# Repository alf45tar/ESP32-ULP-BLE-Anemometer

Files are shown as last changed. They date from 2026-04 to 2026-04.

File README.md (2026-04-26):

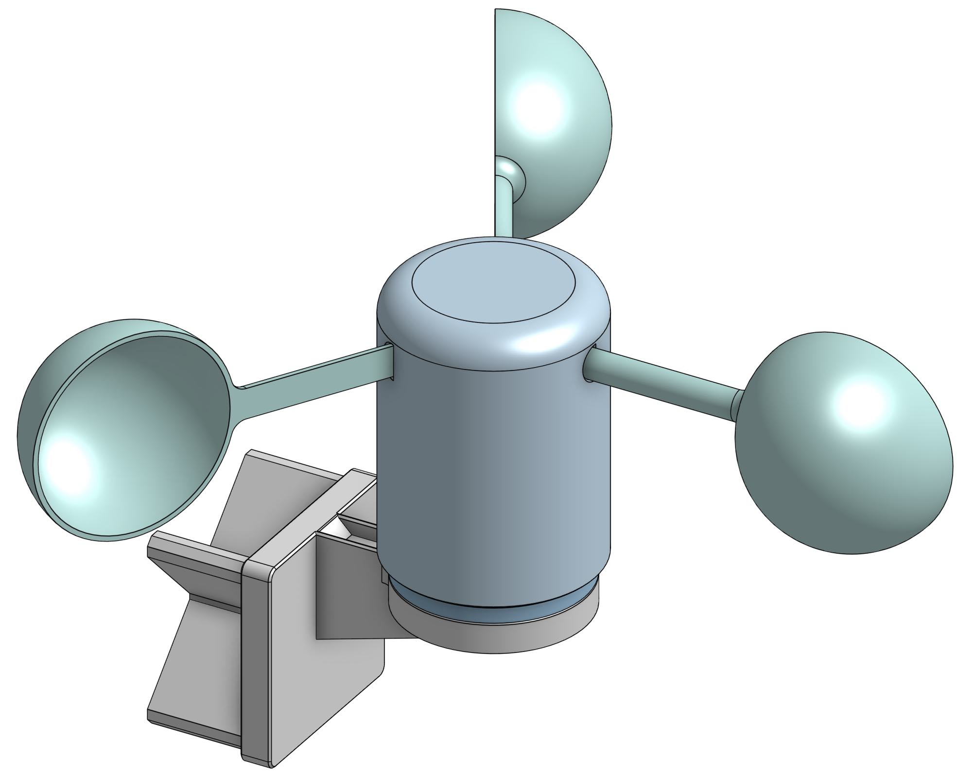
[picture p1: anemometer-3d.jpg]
3D Printed Anemometer


# 🌀 ESP32 ULP BLE Anemometer (BTHome V2)

A high-efficiency, battery-powered wind speed sensor (Anemometer) using the ESP32. This project leverages the **ULP (Ultra-Low Power) co-processor** to monitor wind pulses while the main CPU is in Deep Sleep, allowing for years of battery life.

## 🚀 Key Features

  * **Ultra-Low Power:** Can be as low as **\~15µA** in deep sleep on the ESP32 alone. Actual current depends on the board and any attached hardware. The main cores only wake up to calculate and transmit data.
  * **BTHome V2 Protocol:** Works natively with **Home Assistant** via Bluetooth—no custom integration or ESPHome YAML required. See [bthome.io](https://bthome.io).
  * **Intelligent Reporting:**
      * **Wind Detected:** Typically reports on the next 5-second wake cycle while wind is present.
      * **Change Detection:** Tries to report a speed change as soon as it is noticed on the next wake cycle.
      * **Heartbeat:** Sends a periodic "still alive" update, usually about every 60 seconds during calm periods.
  * **Hardware Debouncing:** ULP-based software sampling filters out mechanical reed switch "bounce."

-----

## 🛠 Hardware Requirements

1.  **ESP32 or ESP32-S3 Board**.
    * For ESP32-C6 check the [ESP32-C6](https://github.com/alf45tar/Anemometer) anemometer project.
3.  **Anemometer** (3-cup type with a Reed Switch).
4.  **Battery:** Li-ion 18650 or LiPo.

### Bill of Materials

| Item | Quantity | Notes |
| :--- | :--- | :--- |
| ESP32 board | 1 | Use a board with an onboard battery sensor (divider) if possible |
| 3D-printed anemometer | 1 | Main wind-sensing body |
| 608 bearing 8x22x7 mm | 1 | Very common bearing for shaft support |
| M3 heat-set insert | 1 | For connecting the main body to the support |
| M3 hex socket cap screw M3x12 | 1 | Fastens the main body to the support |
| Reed switch | 1 | Wind pulse sensor |
| Magnet 6x3 mm | 2 | For triggering the reed switch |
| Battery | 1 | Li-ion 18650 or LiPo |

### Wiring

Connect the reed switch between SENSOR_GPIO pin and GND.

For battery monitoring, a board with an onboard battery divider is recommended.

-----

## 💻 Installation

### 1\. Libraries Required

Install the following libraries via the Arduino Library Manager:

  * [**NimBLE-Arduino**](https://github.com/h2zero/NimBLE-Arduino) (Lightweight Bluetooth LE)
  * [**BTHomeV2-Arduino**](https://github.com/deeja/BTHomeV2-Arduino) (BTHome data formatting)

### 2\. Configuration

Adjust the constants at the top of the sketch to match your hardware:

```cpp
const float RADIUS_METERS      = 0.071; // Center to cup middle
const float CALIBRATION_FACTOR = 2.5;   // Aerodynamic factor
const int   PULSES_PER_REV     = 2;     // Number of magnets in your sensor
```

**Tuning Guide:**

* **RADIUS_METERS**: Measure from the center of the shaft to the center of a cup.
* **PULSES_PER_REV**: Set this to the number of magnet passes per full revolution.
* **CALIBRATION_FACTOR**: Adjust this if you want accurate wind-speed measurements. Compare the reading against a known wind source or a reference sensor, then increase or decrease this factor until they match closely.

If you are only using the anemometer for threshold-based automation, such as closing an awning with a Shelly device, a precise calibration is usually not required. In that case, a stable and repeatable reading is enough to trigger the chosen wind-speed threshold.

### 3\. Flash

Upload the code to your ESP32. Open the Serial Monitor (115200 baud) to verify the "Fresh Boot" and "Deep Sleep" cycles.

-----

## 🏠 Home Assistant Integration

1.  Ensure the **Bluetooth** integration is active in Home Assistant.
2.  The sensor will be automatically discovered as a **BTHome** device named **"Wind Sensor"**.
3.  Add it to your dashboard. The wind speed will appear as a sensor entity in `m/s`.

-----

## 🔌 Shelly Integration

If you are using **Shelly** devices, the anemometer can also be configured as a **virtual component** in your Shelly setup. This does **not** require Home Assistant.

Depending on the Shelly virtual component setup, you may need the ESP32 BLE address.
To print it directly from the board, upload this small sketch and read the value from the Serial Monitor:

```cpp
#include <Arduino.h>
#include <NimBLEDevice.h>

void setup() {
  Serial.begin(115200);
  NimBLEDevice::init("ESP32");
}

void loop() {
  BLEAddress localAddress = NimBLEDevice::getAddress();
  Serial.println(localAddress.toString().c_str());
  delay(1000);
}
```

### Example Use Case

Use the anemometer to automatically close an awning with a **Shelly 2PM Gen3** when wind speed gets too high, without any extra wiring between the wind sensor and the Shelly device. The anemometer broadcasts wind data over BLE, and Shelly handles the automation logic on its side. In this setup, the ESP32 board and battery are hidden inside the square bar, which also supports the anemometer using an interlocking fit (no screw required).

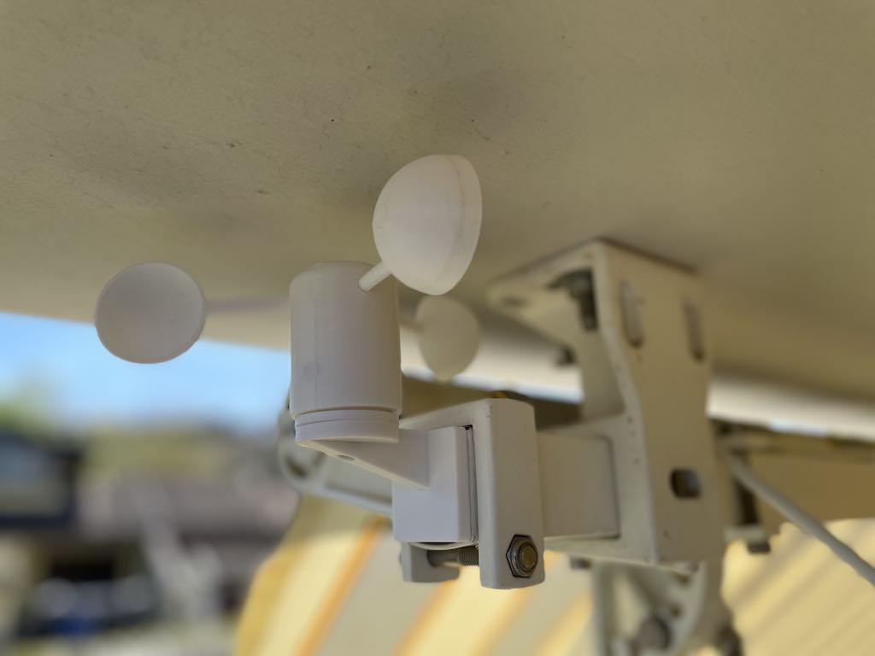
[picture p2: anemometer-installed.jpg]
Anemometer


-----

## 📉 Power Consumption Profile

  * **Deep Sleep (ULP Active):** \~15µA minimum, depending on the board and attached hardware
  * **BLE Transmission (1.5s):** \~100mA
  * **Total Battery Life:** \~1-2 years on a 2500mAh 18650 cell (depending on wind frequency).

-----

## 📜 License

This project is licensed under the MIT License - see the LICENSE file for details.

-----

## 🙌 Credits

  * **NimBLE-Arduino** by [h2zero](https://github.com/h2zero)
  * **BTHome V2** protocol by [bthome.io](https://bthome.io).

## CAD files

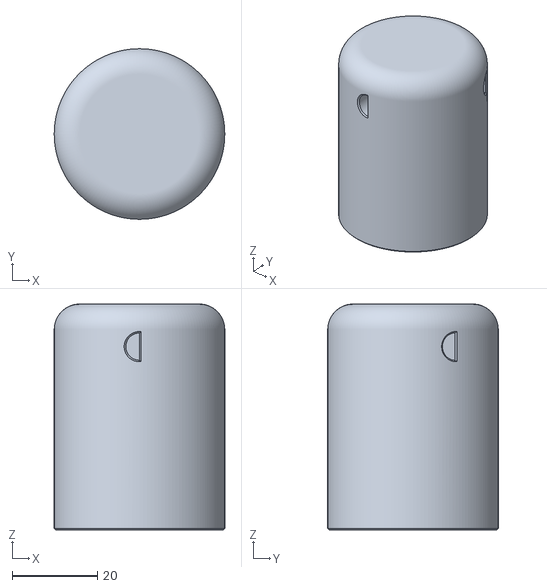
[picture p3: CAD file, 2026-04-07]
Body.stl
40.0 x 40.0 x 53.0

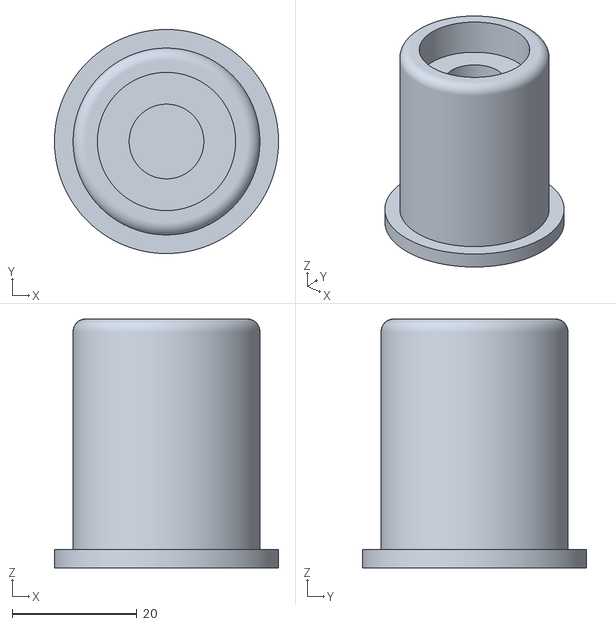
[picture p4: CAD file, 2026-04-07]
Base.stl
36.0 x 36.0 x 40.0

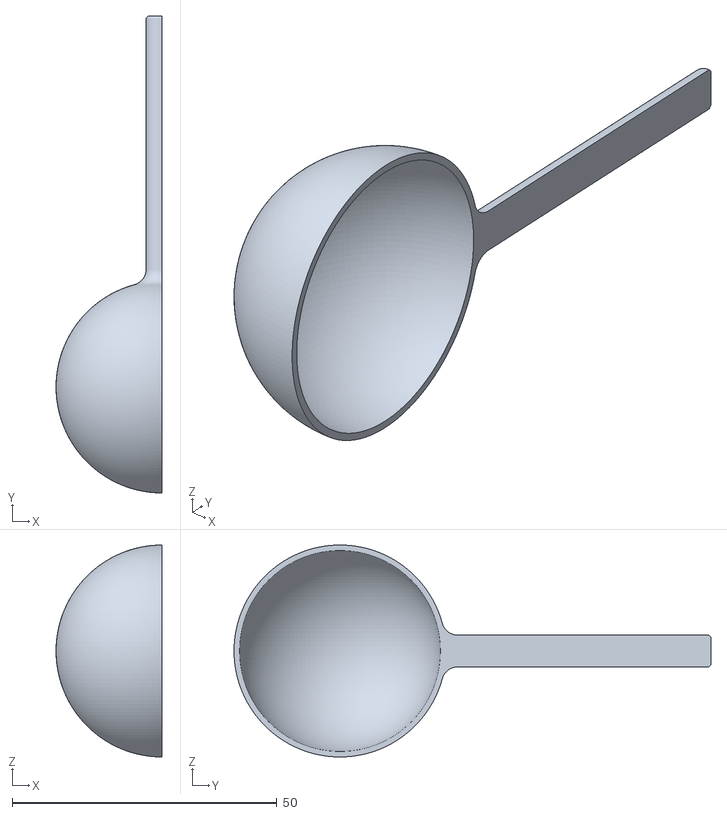
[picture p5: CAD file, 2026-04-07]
Spoon.stl
20.0 x 90.0 x 40.0

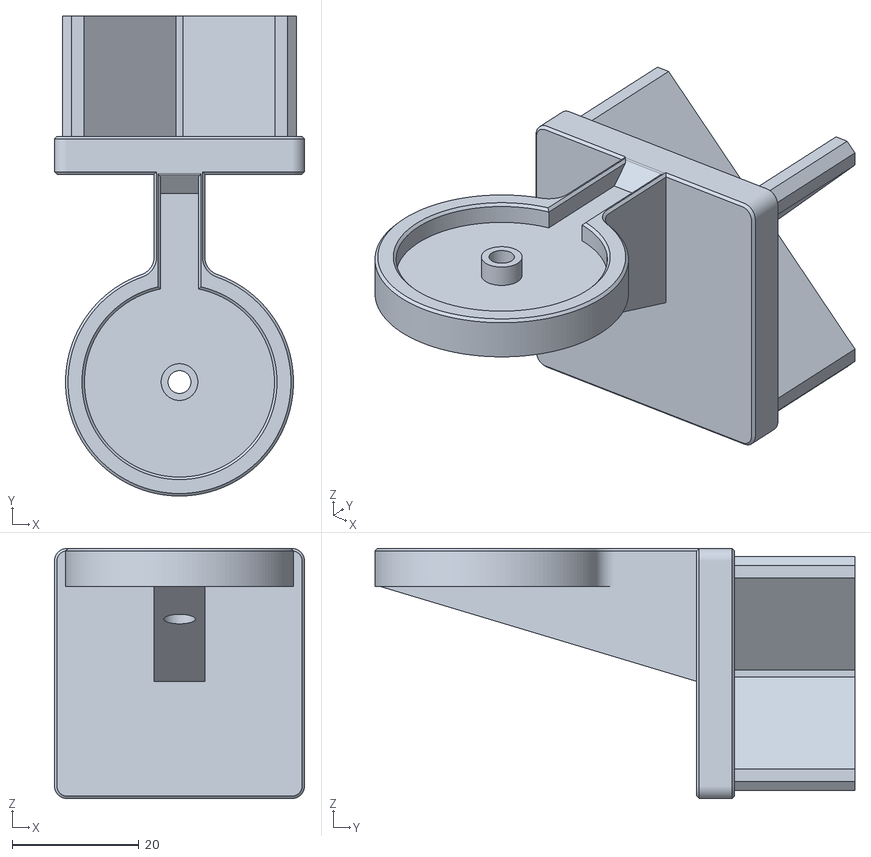
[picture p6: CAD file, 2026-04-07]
Support.stl
39.5 x 75.8 x 39.5

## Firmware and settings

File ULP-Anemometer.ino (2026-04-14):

/*
 * ======================================================================================
 * ESP32 ULTRA-LOW POWER (ULP) BLE ANEMOMETER
 * ======================================================================================
 * * DESCRIPTION:
 *    This firmware transforms an ESP32/ESP32-S3 into a high-efficiency wind speed sensor.
 *    It uses the ULP (Ultra-Low Power) co-processor to count pulses from a reed
 *    switch while the main ESP32 cores are in Deep Sleep.
 * * HOW IT WORKS:
 *    1. SLEEP: The ESP32 enters Deep Sleep (consuming ~10-15µA).
 *    2. ULP MONITORING: The ULP co-processor remains active, sampling GPIO 4
 *        every 10 milliseconds to detect magnet passes (edge detection).
 *    3. WAKEUP: Every 5 seconds, the ESP32 wakes up to process the ULP data.
 *    4. LOGIC ENGINE:
 *        - If Wind Speed > 0: Calculates speed and broadcasts immediately via BLE.
 *        - If Speed Changes: Broadcasts immediately to show the change.
 *        - If No Wind: Skips BLE transmission to save battery, incrementing a counter.
 *        - Heartbeat: Every 60 seconds, it forces a broadcast (even if no wind) so Home
 *          Assistant knows the sensor is still online.
 * * DATA PROTOCOL:
 *    Uses BTHome V2 (Bluetooth Low Energy). Compatible with Home Assistant and Shelly
 * * HARDWARE NOTES:
 *    - Sensor Pin: GPIO 4 (must be an RTC-capable pin).
 *    - Pulses: 2 pulses per revolution (assuming 2 magnets).
 *    - Radius: 0.071m (center to cup middle).
 *    - Calibration: 2.5x factor to compensate for cup drag/aerodynamics.
 * * POWER CONSUMPTION:
 *    - Deep Sleep: ~15µA (it depends by the board, less feautures is better)
 *    - BLE Broadcast (1.5s): ~100mA
 *    - Estimated Battery Life (1000mAh Li-ion): >1 year with 1-minute heartbeats.
 * ======================================================================================
 */

#include <Arduino.h>
#include <BtHomeV2Device.h>
#include "NimBLEDevice.h"

// Conditional headers for ULP
#if defined(CONFIG_IDF_TARGET_ESP32S3)
    #include "esp32s3/ulp.h"
#elif defined(CONFIG_IDF_TARGET_ESP32)
    #include "esp32/ulp.h"
#endif

#include "driver/rtc_io.h"
#include "soc/rtc_io_reg.h"
#include "esp_log.h"
#include "esp_sleep.h"

// Logging tag
static const char *TAG = "ANEMOMETER";

// --------------------------------------------------------------------------------------
// CONFIGURATION & CALIBRATION
// --------------------------------------------------------------------------------------
#define SENSOR_GPIO            GPIO_NUM_4   // Must be RTC-capable
                                            // ESP32:    GPIO 0, 2, 4, 12-15, 25-27, 32-39
                                            // ESP32-S3: GPIO 0-21
                                            // Avoid GPIO 0, 2, 12, and 15 for the sensor as they are "strapping pins"
                                            // and can prevent the ESP32 from booting if held LOW/HIGH by the magnet
const float RADIUS_METERS      = 0.078;     // Distance from center to the middle of the cup (e.g., 5cm = 0.05m)
const float CALIBRATION_FACTOR = 2.5;       // Aerodynamic compensation (usually between 2.0 and 3.0)
const int   PULSES_PER_REV     = 2;         // Set to 2 because we have 2 magnets
const uint64_t SLEEP_TIME      = 5;         // 5 seconds sleep
const int   HEARTBEAT_CYCLES   = 60/SLEEP_TIME; // 12 * 5s = 60s update

#define BATTERY_ADC_PIN         GPIO_NUM_14 // Must be an ADC-capable pin
                                            // Battery measurement (expects a resistor divider to keep ADC voltage <= 3.3V)
const uint8_t  VOLTAGE_DIV_RATIO   = 2;     // Resistor divider -> battery voltage is ADC voltage * 2
const uint32_t BATTERY_MIN         = 3200;  // 3.2V = 0%
const uint32_t BATTERY_MAX         = 4200;  // 4.2V = 100%

uint32_t readBatteryVoltage() {
  /* To ensure accurate ADC readings with high-value resistors, a 0.1uF (100nF)
   * ceramic capacitor MUST be placed between the ADC pin and GND.
   * Without the 0.1uF "reservoir" cap, the 470k
   * source impedance causes a significant voltage drop (sag) during
   * the sampling window, resulting in artificially low readings.
   * Resistor Divider Static Drain: assuming a 470k/470k divider,
   * the continuous leakage current is calculated as:
   *         I ≈ 4.2V / 940,000Ω ≈ 4.5µA
   * This 4.5µA drain is CONTINUOUS, even during deep sleep.
   * This is such a low value that the internal chemical self-discharge
   * of the battery itself probably consumes more.
   */

  // Read the ADC voltage using the built in factory calibration, no conversion needed.
  uint32_t voltage = analogReadMilliVolts(BATTERY_ADC_PIN);
  return voltage * VOLTAGE_DIV_RATIO;
}

uint8_t batteryPercentFromVoltage(uint32_t batteryVoltage) {
  uint32_t safeVoltage = constrain(batteryVoltage, BATTERY_MIN, BATTERY_MAX);
  return map(safeVoltage, BATTERY_MIN, BATTERY_MAX, 0, 100);
}

// --------------------------------------------------------------------------------------
// RTC MEMORY MAPPING (Persists during Deep Sleep)
// --------------------------------------------------------------------------------------
enum {
  VAR_COUNTER,      // RTC_SLOW_MEM[0] - Pulse count from ULP
  VAR_LAST_STATE,   // RTC_SLOW_MEM[1] - ULP internal pin state
  VAR_SKIP_COUNT,   // RTC_SLOW_MEM[2] - Heartbeat timer
  VAR_LAST_SPEED,   // RTC_SLOW_MEM[3] - Speed of the previous wake cycle
  PROG_START        // RTC_SLOW_MEM[4] - Start of ULP code
};

// --------------------------------------------------------------------------------------
// ULP ASSEMBLY PROGRAM
// --------------------------------------------------------------------------------------
void init_ulp_program() {
  int rtc_pin = rtc_io_number_get(SENSOR_GPIO);
  if (rtc_pin < 0) {
    ESP_LOGE(TAG, "GPIO %d is not an RTC IO pin", SENSOR_GPIO);
    return;
  }

  const ulp_insn_t ulp_program[] = {
    M_LABEL(0),                                               // LABEL 0
    // 1. Read current state of RTC GPIO
    I_RD_REG(RTC_GPIO_IN_REG, RTC_GPIO_IN_NEXT_S + rtc_pin, RTC_GPIO_IN_NEXT_S + rtc_pin),
                                                              // R0 = digitalRead(SENSOR_GPIO)
    // 2. Load last state
    I_MOVI(R2, VAR_LAST_STATE),                               // R2 = VAR_LAST_STATE
    I_LD(R1, R2, 0),                                          // R1 = R2*

    // 3. Compare current (R0) and last (R1)
    I_SUBR(R3, R0, R1),                                       // R3 = R0 - R1
    M_BXZ(1),           // If no change, jump to LABEL 1      // IF R3 == 0 GOTO LABEL 1

    // 4. Update last state and increment counter
    I_ST(R0, R2, 0),                                          // R2* = R0
    I_MOVI(R2, VAR_COUNTER),                                  // R2 = VAR_COUNTER
    I_LD(R1, R2, 0),                                          // R1 = R2*
    I_ADDI(R1, R1, 1),                                        // R1 = R1 + 1
    I_ST(R1, R2, 0),                                          // R2* = R1

    M_LABEL(1),                                               // LABEL 1
    #if defined(CONFIG_IDF_TARGET_ESP32S3)
      I_HALT()                                                // Stop and wait for the next timer trigger
    #else
      I_DELAY(85000),                                         // WAIT 10ms (85000/8.5MHz) simple debouce
      M_BX(0),                                                // GOTO LABEL 0
    #endif
  };

  memset(RTC_SLOW_MEM, 0, CONFIG_ULP_COPROC_RESERVE_MEM);
  size_t size = sizeof(ulp_program) / sizeof(ulp_insn_t);
  ulp_process_macros_and_load(PROG_START, ulp_program, &size);

  #if defined(CONFIG_IDF_TARGET_ESP32S3)
    ulp_set_wakeup_period(0, 10000); // Trigger ULP program every 10ms (100Hz)
  #endif

  rtc_gpio_init(SENSOR_GPIO);
  rtc_gpio_set_direction(SENSOR_GPIO, RTC_GPIO_MODE_INPUT_ONLY);
  rtc_gpio_pullup_en(SENSOR_GPIO);
  rtc_gpio_pulldown_dis(SENSOR_GPIO);

  ulp_run(PROG_START);
}

// --------------------------------------------------------------------------------------
// MAIN EXECUTION (Wakeup Logic)
// --------------------------------------------------------------------------------------
void setup() {
  // Logging is already initialized by ESP-IDF at boot
  ESP_LOGI(TAG, "Wake up every %d sec to process the ULP data", SLEEP_TIME);

  esp_sleep_wakeup_cause_t cause = esp_sleep_get_wakeup_cause();

  if (cause == ESP_SLEEP_WAKEUP_TIMER) {
    uint32_t transitions = RTC_SLOW_MEM[VAR_COUNTER] & 0xFFFF;
    uint32_t skip_count = RTC_SLOW_MEM[VAR_SKIP_COUNT] & 0xFFFF;
    uint32_t last_speed_int = RTC_SLOW_MEM[VAR_LAST_SPEED] & 0xFFFF;

    // 1. Calculate current speed
    float totalPulses = (float)transitions / 2.0;
    float totalTurns = totalPulses / (float)PULSES_PER_REV;
    float rps = totalTurns / (float)SLEEP_TIME;
    float speedMPS = rps * (2 * PI * RADIUS_METERS) * CALIBRATION_FACTOR;

    // Convert to int for easy comparison (e.g., 2.45 m/s becomes 245)
    uint32_t current_speed_int = (uint32_t)(speedMPS * 100);

    // 2. Evaluate Conditions
    bool speed_changed = (current_speed_int != last_speed_int);
    bool heartbeat = (skip_count >= (HEARTBEAT_CYCLES - 1));

    if (speed_changed || heartbeat) {
      // Broadcast logic
      RTC_SLOW_MEM[VAR_COUNTER] = 0;
      RTC_SLOW_MEM[VAR_SKIP_COUNT] = 0;
      RTC_SLOW_MEM[VAR_LAST_SPEED] = current_speed_int;

      // Battery is sampled only when you actually advertise, not on every wake cycle
      // A single analog read is negligible in terms of power consumption
      // compared to a BLE transmission. It is not the primary battery drain.
      uint32_t batteryVoltage = readBatteryVoltage();
      uint8_t  batteryPercent = batteryPercentFromVoltage(batteryVoltage);

      // Start BLE advertisement
      NimBLEDevice::init("Wind Sensor");
      NimBLEAdvertising *pAdvertising = NimBLEDevice::getAdvertising();

      BtHomeV2Device btHome("Anemometer", "Wind Sensor", false);
      btHome.addSpeedMs(speedMPS);
      btHome.addBatteryPercentage(batteryPercent);

      uint8_t advDataRaw[MAX_ADVERTISEMENT_SIZE];
      size_t size = btHome.getAdvertisementData(advDataRaw);
      NimBLEAdvertisementData pAdvData;
      std::vector<uint8_t> data(advDataRaw, advDataRaw + size);
      pAdvData.addData(data);

      pAdvertising->setAdvertisementData(pAdvData);
      pAdvertising->start();

      std::string deviceAddr = NimBLEDevice::getAddress().toString();
      ESP_LOGI(TAG, "Pulses: %d | RPS: %.2f | Wind Speed: %.2f m/s | Battery: %d%% (%.2fV) | MAC: %s (Reason: %s)",
          (int)transitions/2, rps, speedMPS, batteryPercent, (float)batteryVoltage/1000.0, deviceAddr.c_str(), speed_changed ? "Change" : "Heartbeat");

      delay(1500); // Wait for scanner to catch the change

      pAdvertising->stop();
      NimBLEDevice::deinit(true);
    } else {
      // Silent cycle: increment heartbeat timer
      RTC_SLOW_MEM[VAR_SKIP_COUNT] = skip_count + 1;
      ESP_LOGI(TAG, "Nothing to process");
    }

  } else {
    // First boot
    init_ulp_program();
  }

  // Go back to sleep
  ESP_LOGI(TAG, "Entering Deep Sleep");
  // Wake me up every SLEEP_TIME uS
  esp_sleep_enable_timer_wakeup(SLEEP_TIME*1000*1000);

  // Keep the RTC peripherals powered for the ULP to read the GPIOs
  esp_sleep_pd_config(ESP_PD_DOMAIN_RTC_PERIPH, ESP_PD_OPTION_ON);

  esp_deep_sleep_start();
}


void loop() {} // Unused in Deep Sleep flow

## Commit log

2026-04-05 Revise README for ESP32 ULP BLE Anemometer
    Expanded project details and added installation instructions.
2026-04-06 Battery monitoring functionality
2026-04-06 Update README with enhanced power consumption details and add Shelly integration section
2026-04-06 Refactor GPIO pin definitions and enhance logging for setup and battery monitoring
2026-04-06 Add instructions for retrieving ESP32 BLE address for Shelly integration
2026-04-07 Update README with Bill of Materials and wiring instructions; add images for anemometer
2026-04-07 Update README to clarify resistor requirements and enhance example use case for Shelly integration
2026-04-07 Add STL files for Base, Body, Spoon, and Support components
    [Base.stl, Body.stl, Spoon.stl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]
2026-04-08 Fix GPIO pin definition for sensor and improve battery voltage reading logic
    [ULP-Anemometer.ino]
2026-04-08 Update README and code for ESP32-S3 support and improve logging
2026-04-09 Unified code for ESP32 and ESP32-S3
2026-04-26 Update hardware requirements and bill of materials
